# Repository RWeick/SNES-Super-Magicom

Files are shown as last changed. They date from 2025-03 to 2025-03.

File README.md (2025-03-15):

# SNES-Super-Magicom
The Kicad files for the SNES Super Magicom

PCB Thicknesses: 
Mainboard - 1.6 mm
RAM Board - 1.6 mm
System Connector Board - 1.2 mm

The system connector board has been modified to allow for the HiROM mod to be installed. Jumpers are labeled to facilitate operation with or without the mod.

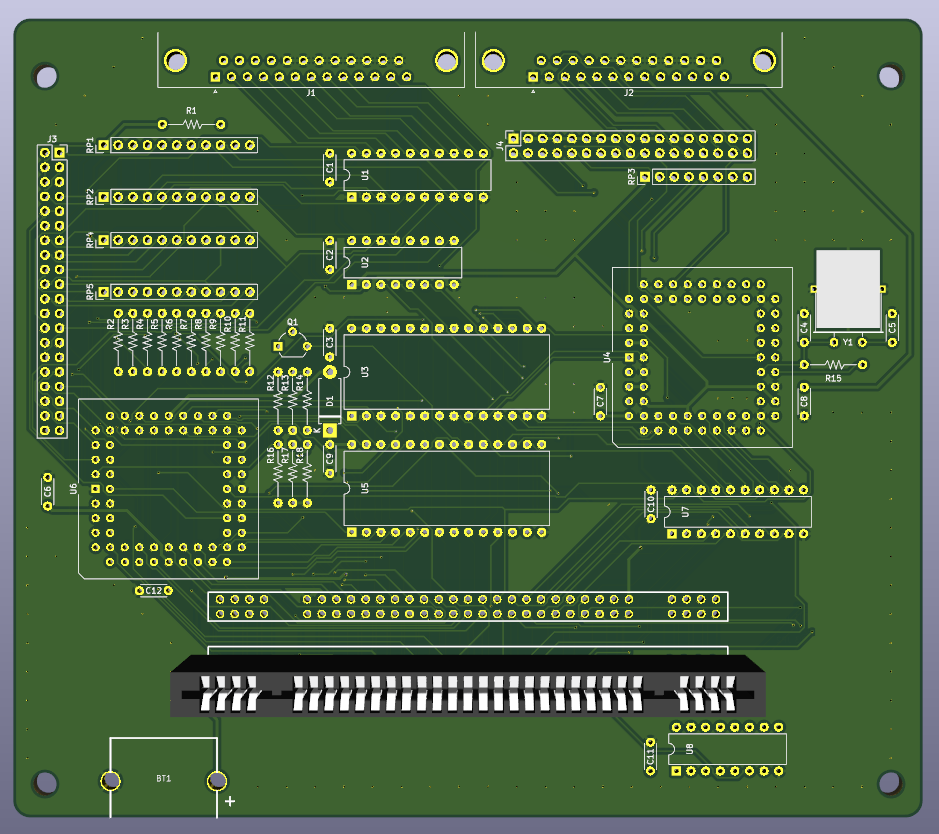
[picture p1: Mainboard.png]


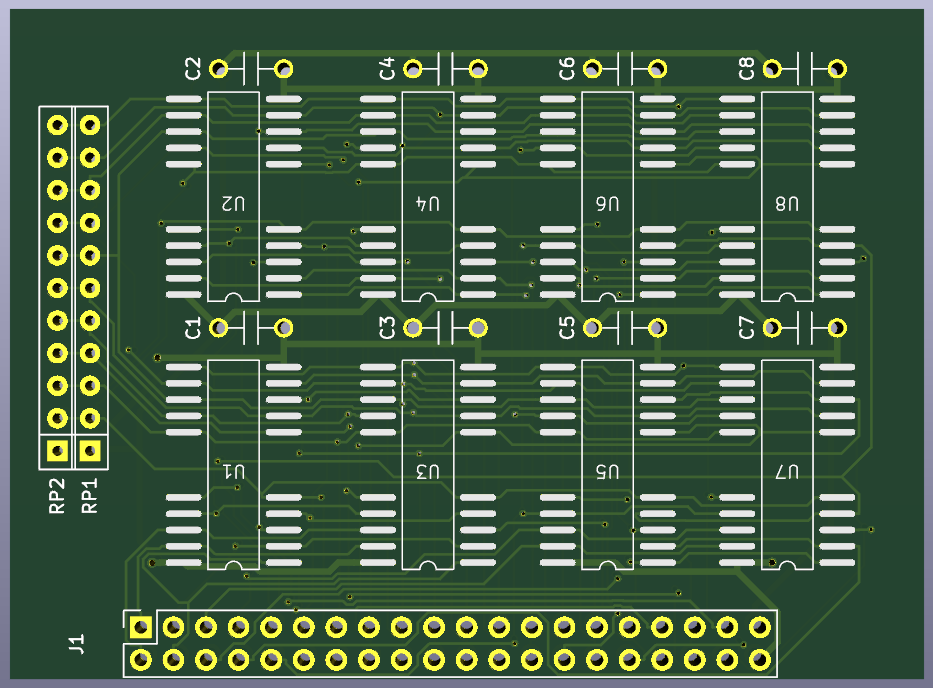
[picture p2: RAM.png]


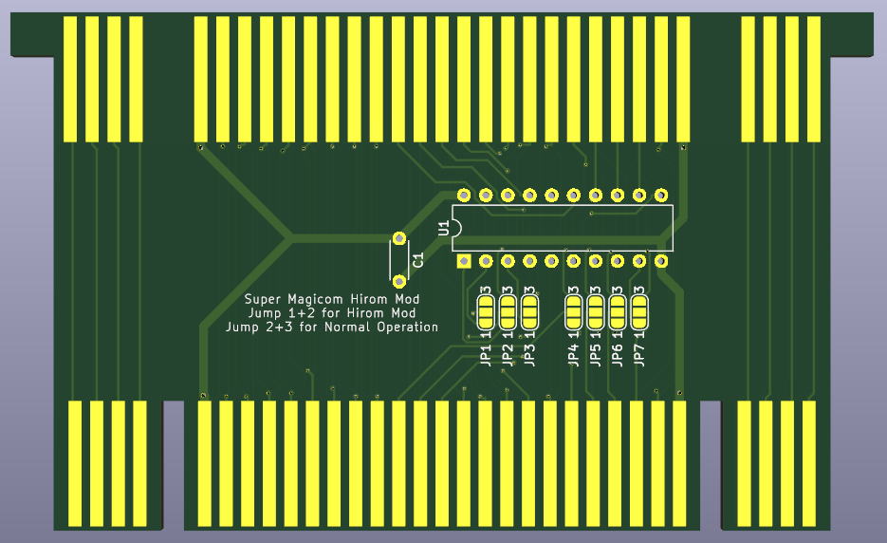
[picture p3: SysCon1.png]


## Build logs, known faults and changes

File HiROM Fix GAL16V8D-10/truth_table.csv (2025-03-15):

/cart_in | a23_in | a22_in | a21_in | a20_in | a17_in | a16_in | a15_in | a14_in | a13_in | - | n/c(16) | /cart_out | a22_out | a21_out | a20_out | a15_out | a14_out | a13_out | - | sourceAddress | - | targetAddress | - | n/c(16)_calc | /cart_out_calc | a22_out_calc | a21_out_calc | a20_out_calc | a15_out_calc | a14_out_calc | a13_out_calc | - | source-target diff? | calc-target match? | 0 | 0 | 0 | 0 | 0 | 0 | 0 | 0 | 0 | 0 | - | 1 | 0 | 0 | 0 | 0 | 0 | 0 | 0 | - | 0x000000 | - | 0x000000 | - | 1
0 | 0 | 0 | 0 | 0 | 0 | 0 | 0 | 0 | 1 | - | 1 | 0 | 0 | 0 | 0 | 0 | 0 | 1 | - | 0x002000 | - | 0x002000 | - | 1 | 0 | 0 | 0 | 0 | 0 | 0 | 1 | - |  | OK
0 | 0 | 0 | 0 | 0 | 0 | 0 | 0 | 1 | 0 | - | 1 | 0 | 0 | 0 | 0 | 0 | 1 | 0 | - | 0x004000 | - | 0x004000 | - | 1 | 0 | 0 | 0 | 0 | 0 | 1 | 0 | - |  | OK
0 | 0 | 0 | 0 | 0 | 0 | 0 | 0 | 1 | 1 | - | 1 | 0 | 0 | 0 | 0 | 0 | 1 | 1 | - | 0x006000 | - | 0x006000 | - | 1 | 0 | 0 | 0 | 0 | 0 | 1 | 1 | - |  | OK
0 | 0 | 0 | 0 | 0 | 0 | 0 | 1 | 0 | 0 | - | 1 | 0 | 0 | 0 | 0 | 1 | 0 | 0 | - | 0x008000 | - | 0x008000 | - | 1 | 0 | 0 | 0 | 0 | 1 | 0 | 0 | - |  | OK
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

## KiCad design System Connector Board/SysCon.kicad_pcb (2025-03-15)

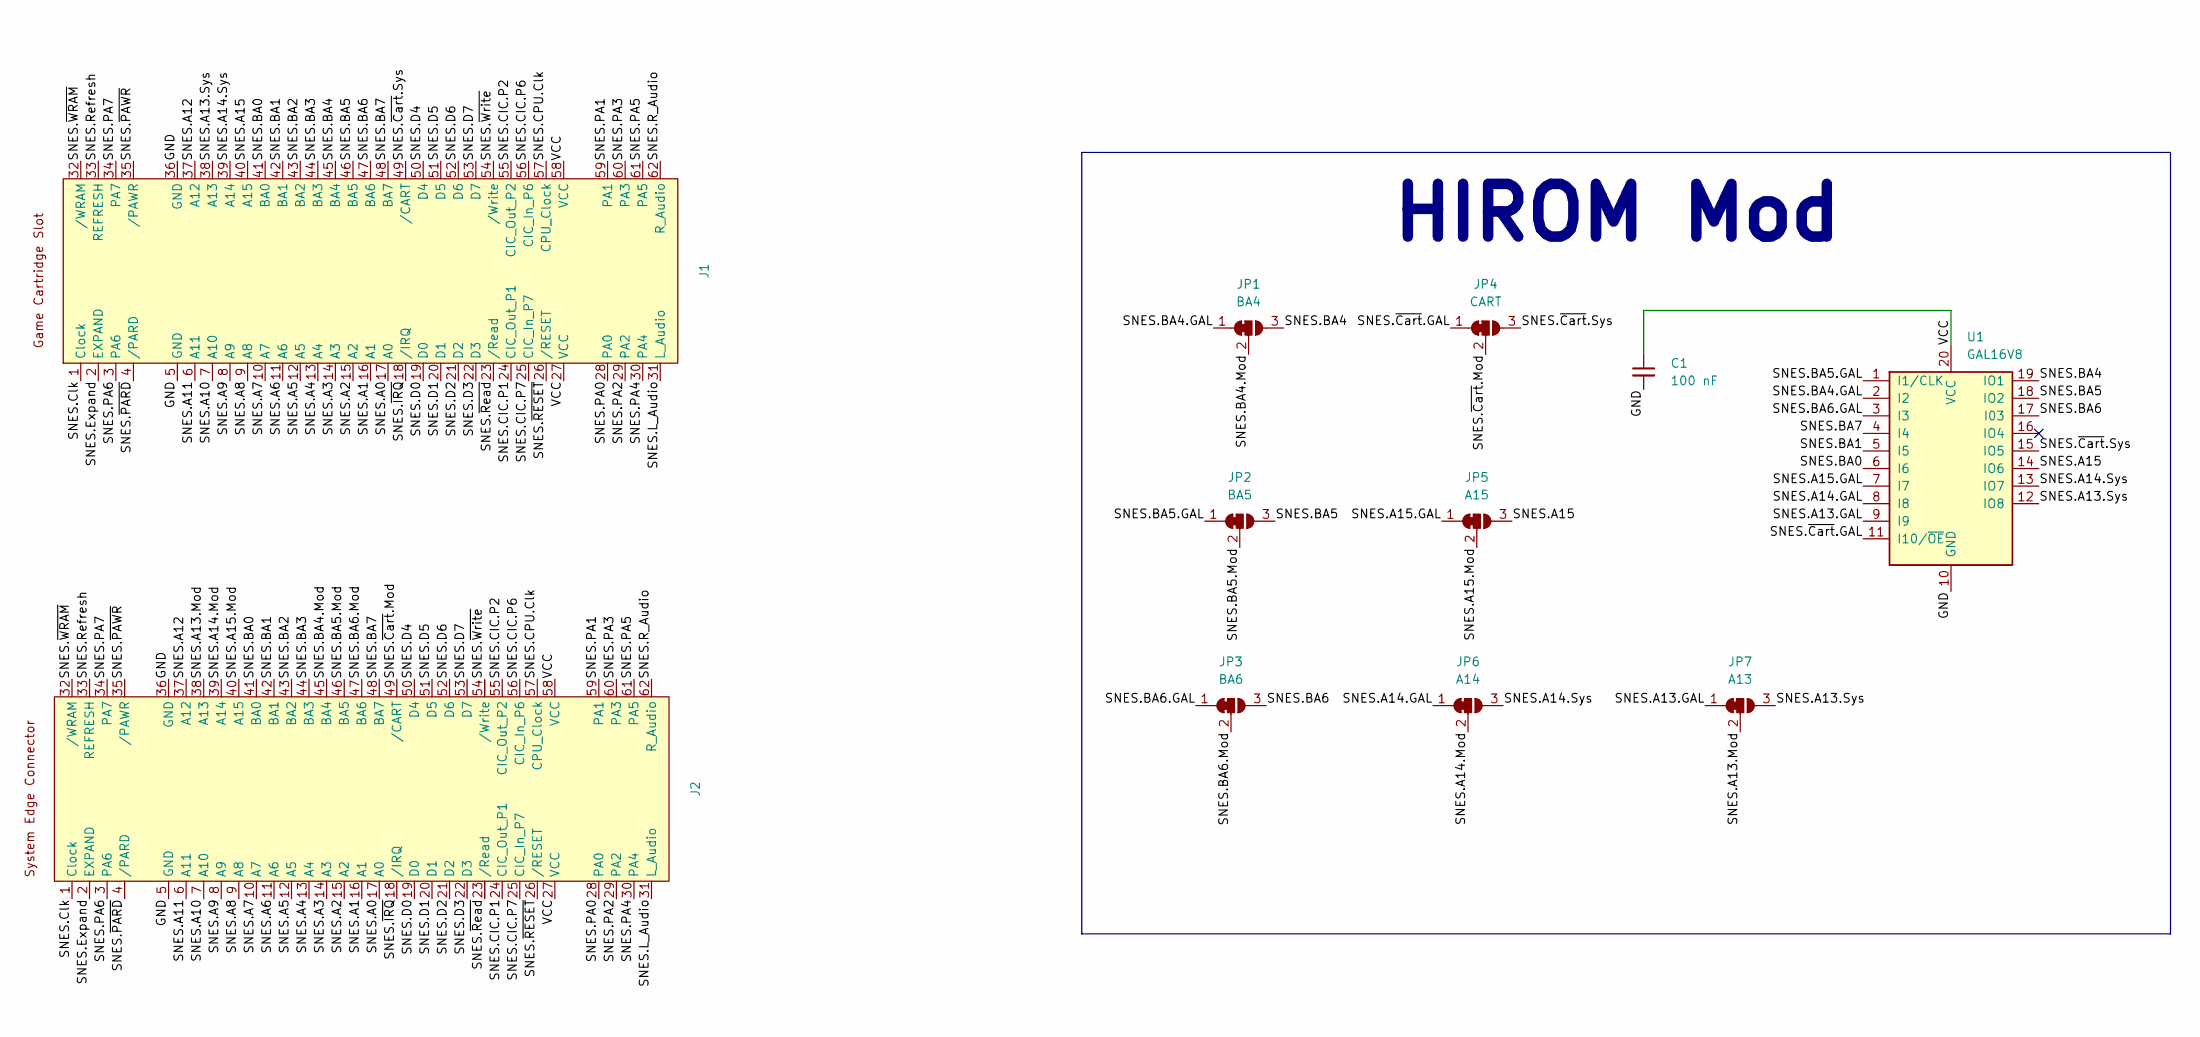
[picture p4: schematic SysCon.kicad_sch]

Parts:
C1: 100 nF; C_Disc_D4.3mm_W1.9mm_P5.00mm
J1: Top Connector
J2: Bottom Connector
JP1: BA4; SolderJumper-3_P1.3mm_Open_RoundedPad1.0x1.5mm_NumberLabels
JP2: BA5; SolderJumper-3_P1.3mm_Open_RoundedPad1.0x1.5mm_NumberLabels
JP3: BA6; SolderJumper-3_P1.3mm_Open_RoundedPad1.0x1.5mm_NumberLabels
JP4: CART; SolderJumper-3_P1.3mm_Open_RoundedPad1.0x1.5mm_NumberLabels
JP5: A15; SolderJumper-3_P1.3mm_Open_RoundedPad1.0x1.5mm_NumberLabels
JP6: A14; SolderJumper-3_P1.3mm_Open_RoundedPad1.0x1.5mm_NumberLabels
JP7: A13; SolderJumper-3_P1.3mm_Open_RoundedPad1.0x1.5mm_NumberLabels
U1: GAL16V8; DIP-20_W7.62mm

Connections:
/GND: C1.2, J1.5 (GND), J1.36 (GND), J2.5 (GND), J2.36 (GND), U1.10 (GND)
/SNES.A0: J1.17 (A0), J2.17 (A0)
/SNES.A1: J1.16 (A1), J2.16 (A1)
/SNES.A2: J1.15 (A2), J2.15 (A2)
/SNES.A3: J1.14 (A3), J2.14 (A3)
/SNES.A4: J1.13 (A4), J2.13 (A4)
/SNES.A5: J1.12 (A5), J2.12 (A5)
/SNES.A6: J1.11 (A6), J2.11 (A6)
/SNES.A7: J1.10 (A7), J2.10 (A7)
/SNES.A8: J1.9 (A8), J2.9 (A8)
/SNES.A9: J1.8 (A9), J2.8 (A9)
/SNES.A10: J1.7 (A10), J2.7 (A10)
/SNES.A11: J1.6 (A11), J2.6 (A11)
/SNES.A12: J1.37 (A12), J2.37 (A12)
/SNES.A13.GAL: JP7.1 (A), U1.9 (I9)
/SNES.A13.Mod: J2.38 (A13), JP7.2 (C)
/SNES.A13.Sys: J1.38 (A13), JP7.3 (B), U1.12 (IO8)
/SNES.A14.GAL: JP6.1 (A), U1.8 (I8)
/SNES.A14.Mod: J2.39 (A14), JP6.2 (C)
/SNES.A14.Sys: J1.39 (A14), JP6.3 (B), U1.13 (IO7)
/SNES.A15: J1.40 (A15), JP5.3 (B), U1.14 (IO6)
/SNES.A15.GAL: JP5.1 (A), U1.7 (I7)
/SNES.A15.Mod: J2.40 (A15), JP5.2 (C)
/SNES.BA0: J1.41 (BA0), J2.41 (BA0), U1.6 (I6)
/SNES.BA1: J1.42 (BA1), J2.42 (BA1), U1.5 (I5)
/SNES.BA2: J1.43 (BA2), J2.43 (BA2)
/SNES.BA3: J1.44 (BA3), J2.44 (BA3)
/SNES.BA4: J1.45 (BA4), JP1.3 (B), U1.19 (IO1)
/SNES.BA4.GAL: JP1.1 (A), U1.2 (I2)
/SNES.BA4.Mod: J2.45 (BA4), JP1.2 (C)
/SNES.BA5: J1.46 (BA5), JP2.3 (B), U1.18 (IO2)
/SNES.BA5.GAL: JP2.1 (A), U1.1 (I1/CLK)
/SNES.BA5.Mod: J2.46 (BA5), JP2.2 (C)
/SNES.BA6: J1.47 (BA6), JP3.3 (B), U1.17 (I03)
/SNES.BA6.GAL: JP3.1 (A), U1.3 (I3)
/SNES.BA6.Mod: J2.47 (BA6), JP3.2 (C)
/SNES.BA7: J1.48 (BA7), J2.48 (BA7), U1.4 (I4)
/SNES.CIC.P1: J1.24 (CIC_Out_P1), J2.24 (CIC_Out_P1)
/SNES.CIC.P2: J1.55 (CIC_Out_P2), J2.55 (CIC_Out_P2)
/SNES.CIC.P6: J1.56 (CIC_In_P6), J2.56 (CIC_In_P6)
/SNES.CIC.P7: J1.25 (CIC_In_P7), J2.25 (CIC_In_P7)
/SNES.CPU.Clk: J1.57 (CPU_Clock), J2.57 (CPU_Clock)
/SNES.Clk: J1.1 (Clock), J2.1 (Clock)
/SNES.D0: J1.19 (D0), J2.19 (D0)
/SNES.D1: J1.20 (D1), J2.20 (D1)
/SNES.D2: J1.21 (D2), J2.21 (D2)
/SNES.D3: J1.22 (D3), J2.22 (D3)
/SNES.D4: J1.50 (D4), J2.50 (D4)
/SNES.D5: J1.51 (D5), J2.51 (D5)
/SNES.D6: J1.52 (D6), J2.52 (D6)
/SNES.D7: J1.53 (D7), J2.53 (D7)
/SNES.Expand: J1.2 (EXPAND), J2.2 (EXPAND)
/SNES.L_Audio: J1.31 (L_Audio), J2.31 (L_Audio)
/SNES.PA0: J1.28 (PA0), J2.28 (PA0)
/SNES.PA1: J1.59 (PA1), J2.59 (PA1)
/SNES.PA2: J1.29 (PA2), J2.29 (PA2)
/SNES.PA3: J1.60 (PA3), J2.60 (PA3)
/SNES.PA4: J1.30 (PA4), J2.30 (PA4)
/SNES.PA5: J1.61 (PA5), J2.61 (PA5)
/SNES.PA6: J1.3 (PA6), J2.3 (PA6)
/SNES.PA7: J1.34 (PA7), J2.34 (PA7)
/SNES.R_Audio: J1.62 (R_Audio), J2.62 (R_Audio)
/SNES.Refresh: J1.33 (REFRESH), J2.33 (REFRESH)
/SNES.~Cart.GAL: JP4.1 (A), U1.11 (I10/~OE)
/SNES.~Cart.Mod: J2.49 (/CART), JP4.2 (C)
/SNES.~Cart.Sys: J1.49 (/CART), JP4.3 (B), U1.15 (IO5)
/SNES.~IRQ: J1.18 (/IRQ), J2.18 (/IRQ)
/SNES.~PARD: J1.4 (/PARD), J2.4 (/PARD)
/SNES.~PAWR: J1.35 (/PAWR), J2.35 (/PAWR)
/SNES.~RESET: J1.26 (/RESET), J2.26 (/RESET)
/SNES.~Read: J1.23 (/Read), J2.23 (/Read)
/SNES.~WRAM: J1.32 (/WRAM), J2.32 (/WRAM)
/SNES.~Write: J1.54 (/Write), J2.54 (/Write)
/VCC: C1.1, J1.27 (VCC), J1.58 (VCC), J2.27 (VCC), J2.58 (VCC), U1.20 (VCC)

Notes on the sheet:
HIROM Mod

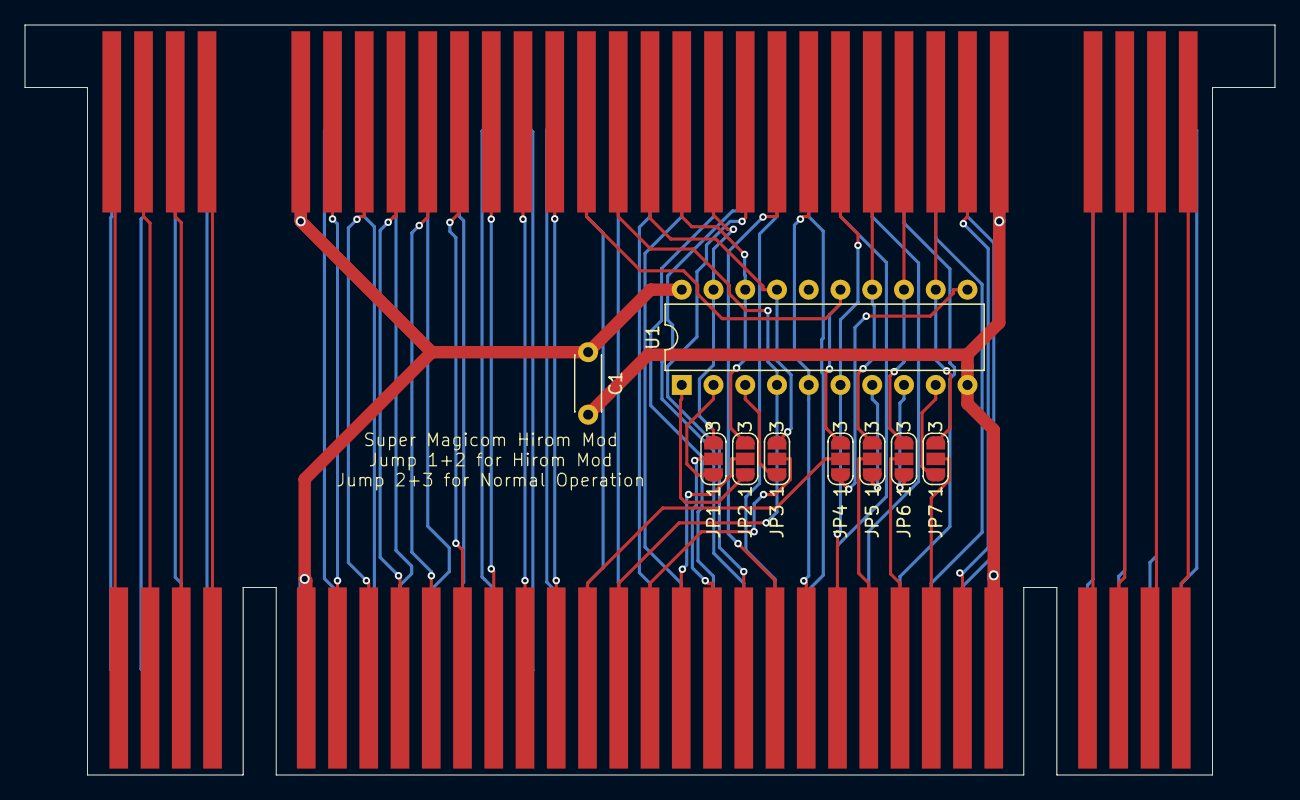
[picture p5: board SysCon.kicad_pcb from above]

Board: 2 copper layers, 100.0 x 60.0 mm, 11 parts (0 on the bottom side), 74 nets.

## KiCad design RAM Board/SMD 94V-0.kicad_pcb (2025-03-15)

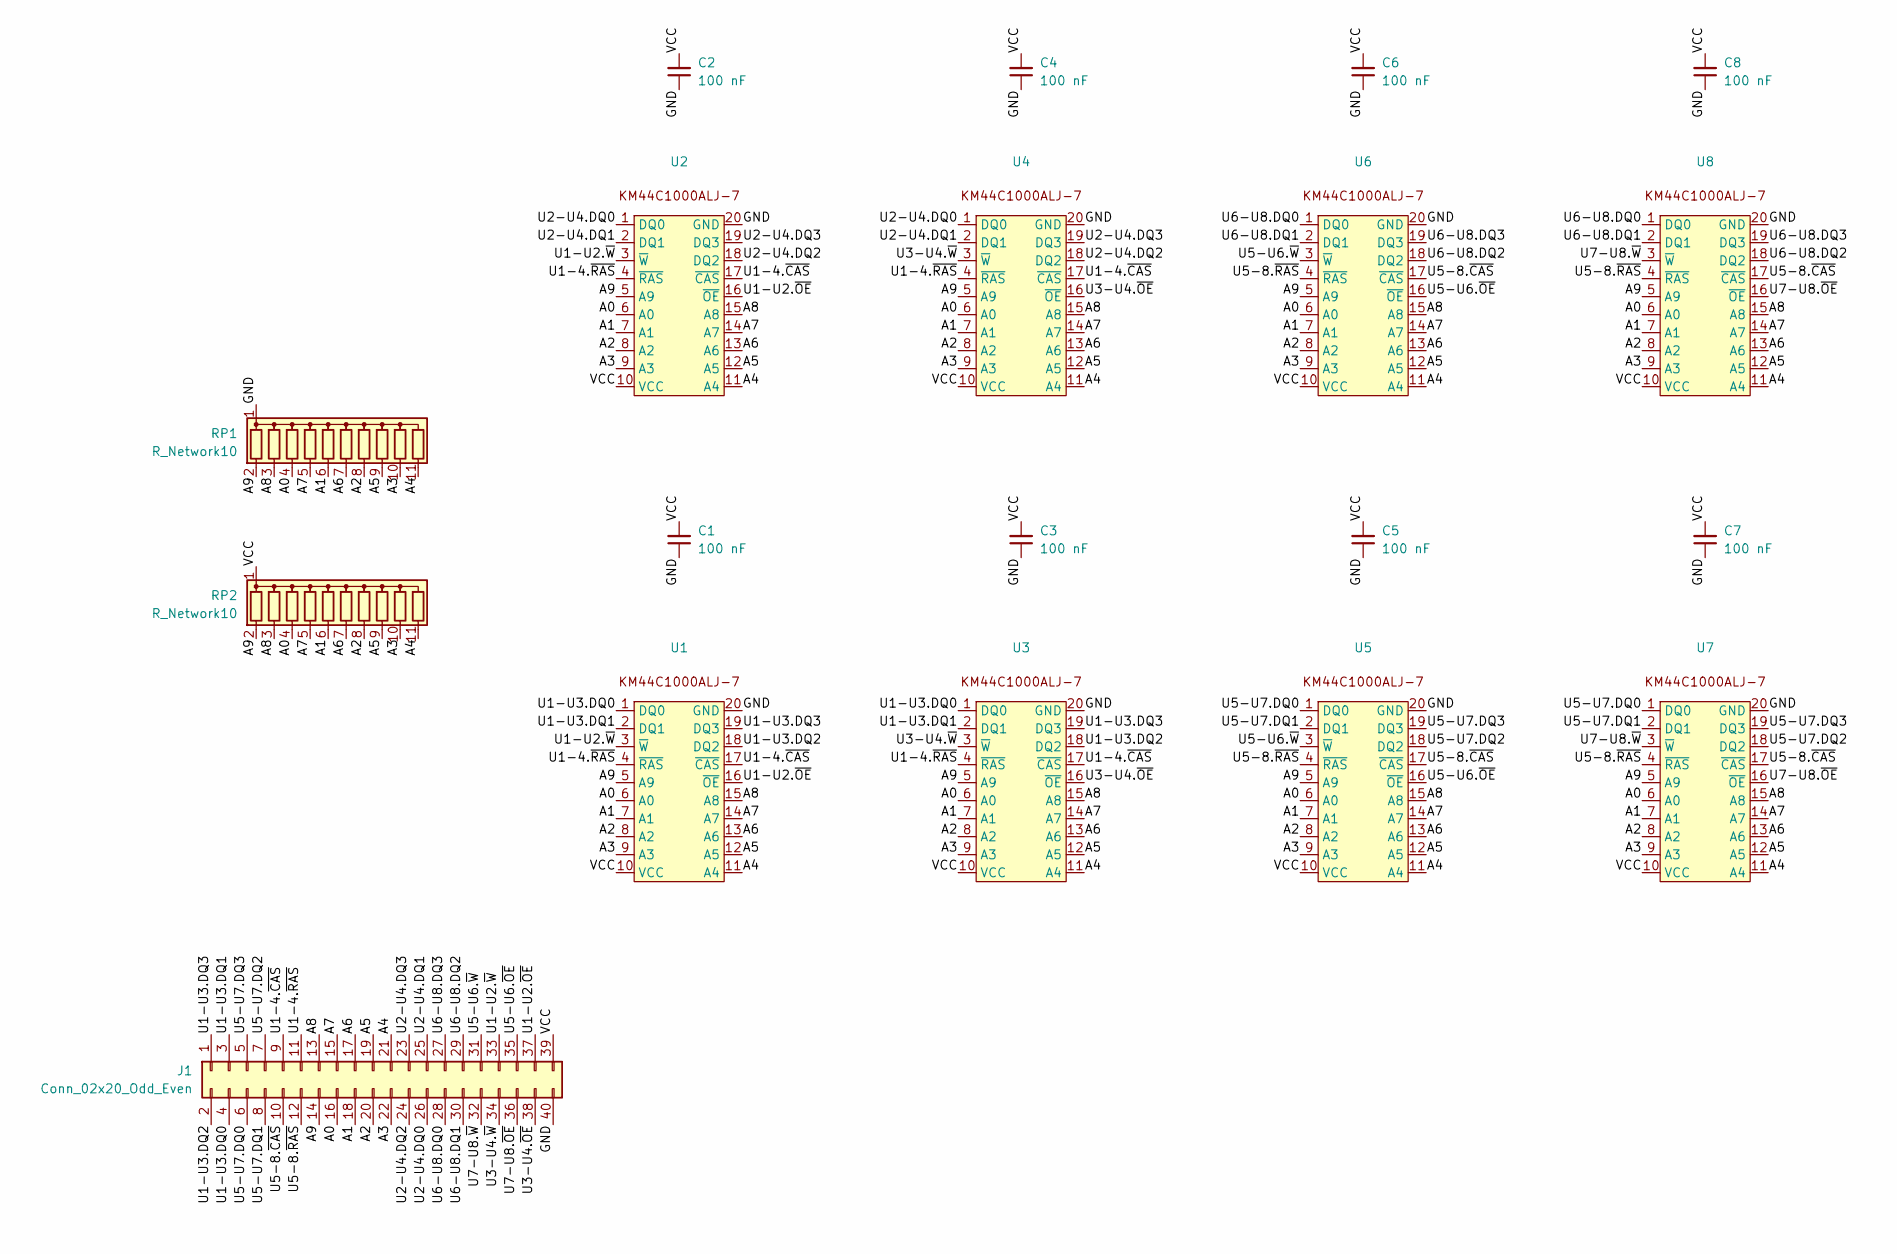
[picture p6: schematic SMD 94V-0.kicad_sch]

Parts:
C1, C2, C3, C4, C5, C6, C7, C8: 100 nF; Capacitor
J1: Conn_02x20_Odd_Even; PinHeader_2x20_P2.54mm_Vertical
RP1, RP2: R_Network10; R_Array_SIP11
U1, U2, U3, U4, U5, U6, U7, U8: KM44C1000ALJ-7

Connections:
/A0: J1.16, RP1.4 (R3), RP2.4 (R3), U1.6 (A0), U2.6 (A0), U3.6 (A0), U4.6 (A0), U5.6 (A0), U6.6 (A0), U7.6 (A0), U8.6 (A0)
/A1: J1.18, RP1.6 (R5), RP2.6 (R5), U1.7 (A1), U2.7 (A1), U3.7 (A1), U4.7 (A1), U5.7 (A1), U6.7 (A1), U7.7 (A1), U8.7 (A1)
/A2: J1.20, RP1.8 (R7), RP2.8 (R7), U1.8 (A2), U2.8 (A2), U3.8 (A2), U4.8 (A2), U5.8 (A2), U6.8 (A2), U7.8 (A2), U8.8 (A2)
/A3: J1.22, RP1.10 (R9), RP2.10 (R9), U1.9 (A3), U2.9 (A3), U3.9 (A3), U4.9 (A3), U5.9 (A3), U6.9 (A3), U7.9 (A3), U8.9 (A3)
/A4: J1.21, RP1.11 (R10), RP2.11 (R10), U1.11 (A4), U2.11 (A4), U3.11 (A4), U4.11 (A4), U5.11 (A4), U6.11 (A4), U7.11 (A4), U8.11 (A4)
/A5: J1.19, RP1.9 (R8), RP2.9 (R8), U1.12 (A5), U2.12 (A5), U3.12 (A5), U4.12 (A5), U5.12 (A5), U6.12 (A5), U7.12 (A5), U8.12 (A5)
/A6: J1.17, RP1.7 (R6), RP2.7 (R6), U1.13 (A6), U2.13 (A6), U3.13 (A6), U4.13 (A6), U5.13 (A6), U6.13 (A6), U7.13 (A6), U8.13 (A6)
/A7: J1.15, RP1.5 (R4), RP2.5 (R4), U1.14 (A7), U2.14 (A7), U3.14 (A7), U4.14 (A7), U5.14 (A7), U6.14 (A7), U7.14 (A7), U8.14 (A7)
/A8: J1.13, RP1.3 (R2), RP2.3 (R2), U1.15 (A8), U2.15 (A8), U3.15 (A8), U4.15 (A8), U5.15 (A8), U6.15 (A8), U7.15 (A8), U8.15 (A8)
/A9: J1.14, RP1.2 (R1), RP2.2 (R1), U1.5 (A9), U2.5 (A9), U3.5 (A9), U4.5 (A9), U5.5 (A9), U6.5 (A9), U7.5 (A9), U8.5 (A9)
/GND: C1.1, C2.1, C3.1, C4.1, C5.1, C6.1, C7.1, C8.1, J1.40, RP1.1 (common), U1.20 (GND), U2.20 (GND), U3.20 (GND), U4.20 (GND), U5.20 (GND), U6.20 (GND), U7.20 (GND), U8.20 (GND)
/U1-4.~CAS: J1.9, U1.17 (~CAS), U2.17 (~CAS), U3.17 (~CAS), U4.17 (~CAS)
/U1-4.~RAS: J1.11, U1.4 (~RAS), U2.4 (~RAS), U3.4 (~RAS), U4.4 (~RAS)
/U1-U2.~OE: J1.37, U1.16 (~OE), U2.16 (~OE)
/U1-U2.~W: J1.33, U1.3 (~W), U2.3 (~W)
/U1-U3.DQ0: J1.4, U1.1 (DQ0), U3.1 (DQ0)
/U1-U3.DQ1: J1.3, U1.2 (DQ1), U3.2 (DQ1)
/U1-U3.DQ2: J1.2, U1.18 (DQ2), U3.18 (DQ2)
/U1-U3.DQ3: J1.1, U1.19 (DQ3), U3.19 (DQ3)
/U2-U4.DQ0: J1.26, U2.1 (DQ0), U4.1 (DQ0)
/U2-U4.DQ1: J1.25, U2.2 (DQ1), U4.2 (DQ1)
/U2-U4.DQ2: J1.24, U2.18 (DQ2), U4.18 (DQ2)
/U2-U4.DQ3: J1.23, U2.19 (DQ3), U4.19 (DQ3)
/U3-U4.~OE: J1.38, U3.16 (~OE), U4.16 (~OE)
/U3-U4.~W: J1.34, U3.3 (~W), U4.3 (~W)
/U5-8.~CAS: J1.10, U5.17 (~CAS), U6.17 (~CAS), U7.17 (~CAS), U8.17 (~CAS)
/U5-8.~RAS: J1.12, U5.4 (~RAS), U6.4 (~RAS), U7.4 (~RAS), U8.4 (~RAS)
/U5-U6.~OE: J1.35, U5.16 (~OE), U6.16 (~OE)
/U5-U6.~W: J1.31, U5.3 (~W), U6.3 (~W)
/U5-U7.DQ0: J1.6, U5.1 (DQ0), U7.1 (DQ0)
/U5-U7.DQ1: J1.8, U5.2 (DQ1), U7.2 (DQ1)
/U5-U7.DQ2: J1.7, U5.18 (DQ2), U7.18 (DQ2)
/U5-U7.DQ3: J1.5, U5.19 (DQ3), U7.19 (DQ3)
/U6-U8.DQ0: J1.28, U6.1 (DQ0), U8.1 (DQ0)
/U6-U8.DQ1: J1.30, U6.2 (DQ1), U8.2 (DQ1)
/U6-U8.DQ2: J1.29, U6.18 (DQ2), U8.18 (DQ2)
/U6-U8.DQ3: J1.27, U6.19 (DQ3), U8.19 (DQ3)
/U7-U8.~OE: J1.36, U7.16 (~OE), U8.16 (~OE)
/U7-U8.~W: J1.32, U7.3 (~W), U8.3 (~W)
/VCC: C1.2, C2.2, C3.2, C4.2, C5.2, C6.2, C7.2, C8.2, J1.39, RP2.1 (common), U1.10 (VCC), U2.10 (VCC), U3.10 (VCC), U4.10 (VCC), U5.10 (VCC), U6.10 (VCC), U7.10 (VCC), U8.10 (VCC)

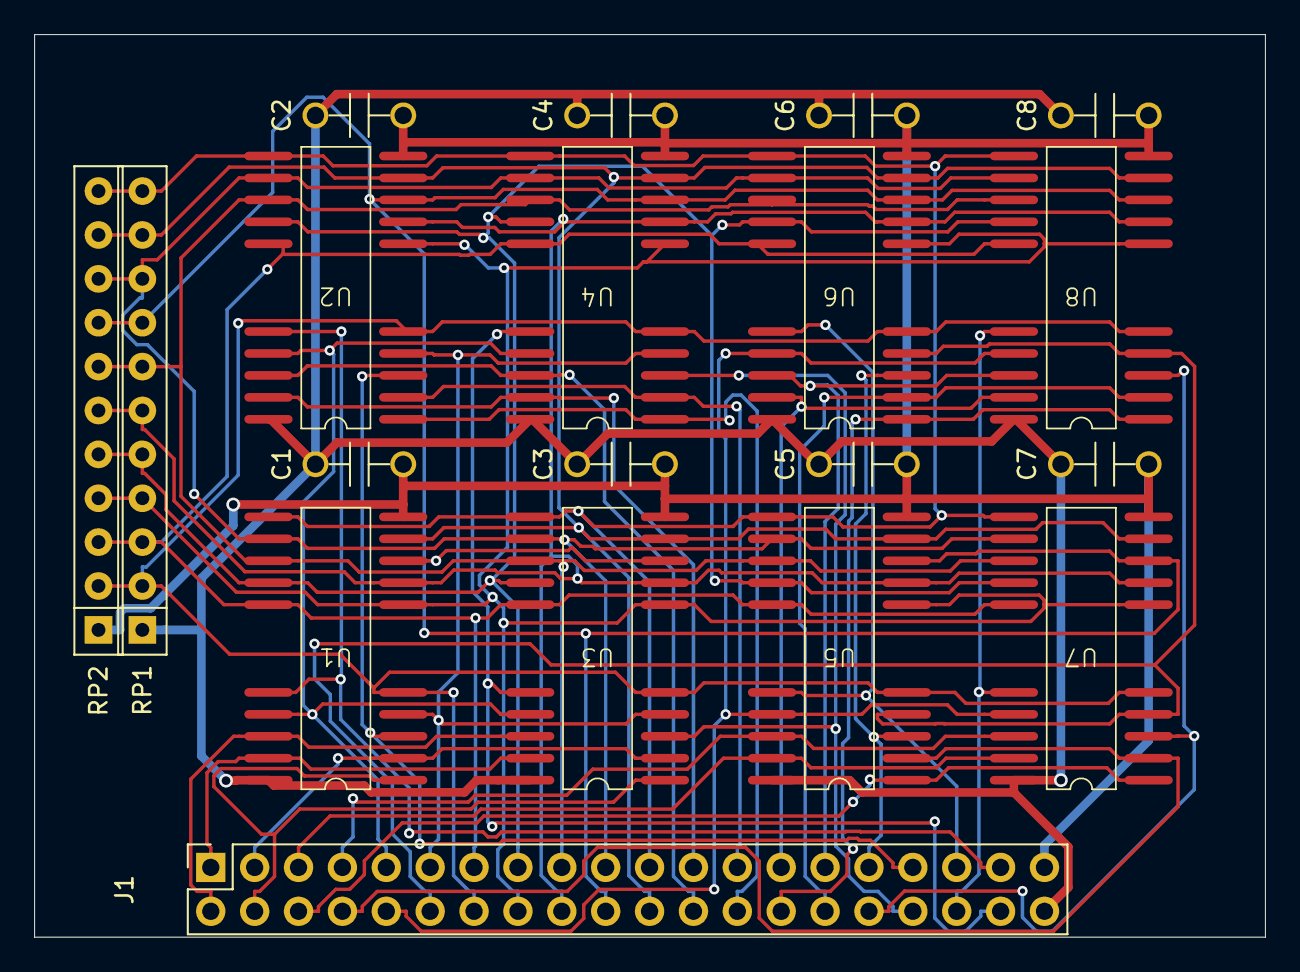
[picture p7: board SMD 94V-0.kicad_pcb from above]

Board: 2 copper layers, 71.3 x 52.2 mm, 19 parts (0 on the bottom side), 40 nets.

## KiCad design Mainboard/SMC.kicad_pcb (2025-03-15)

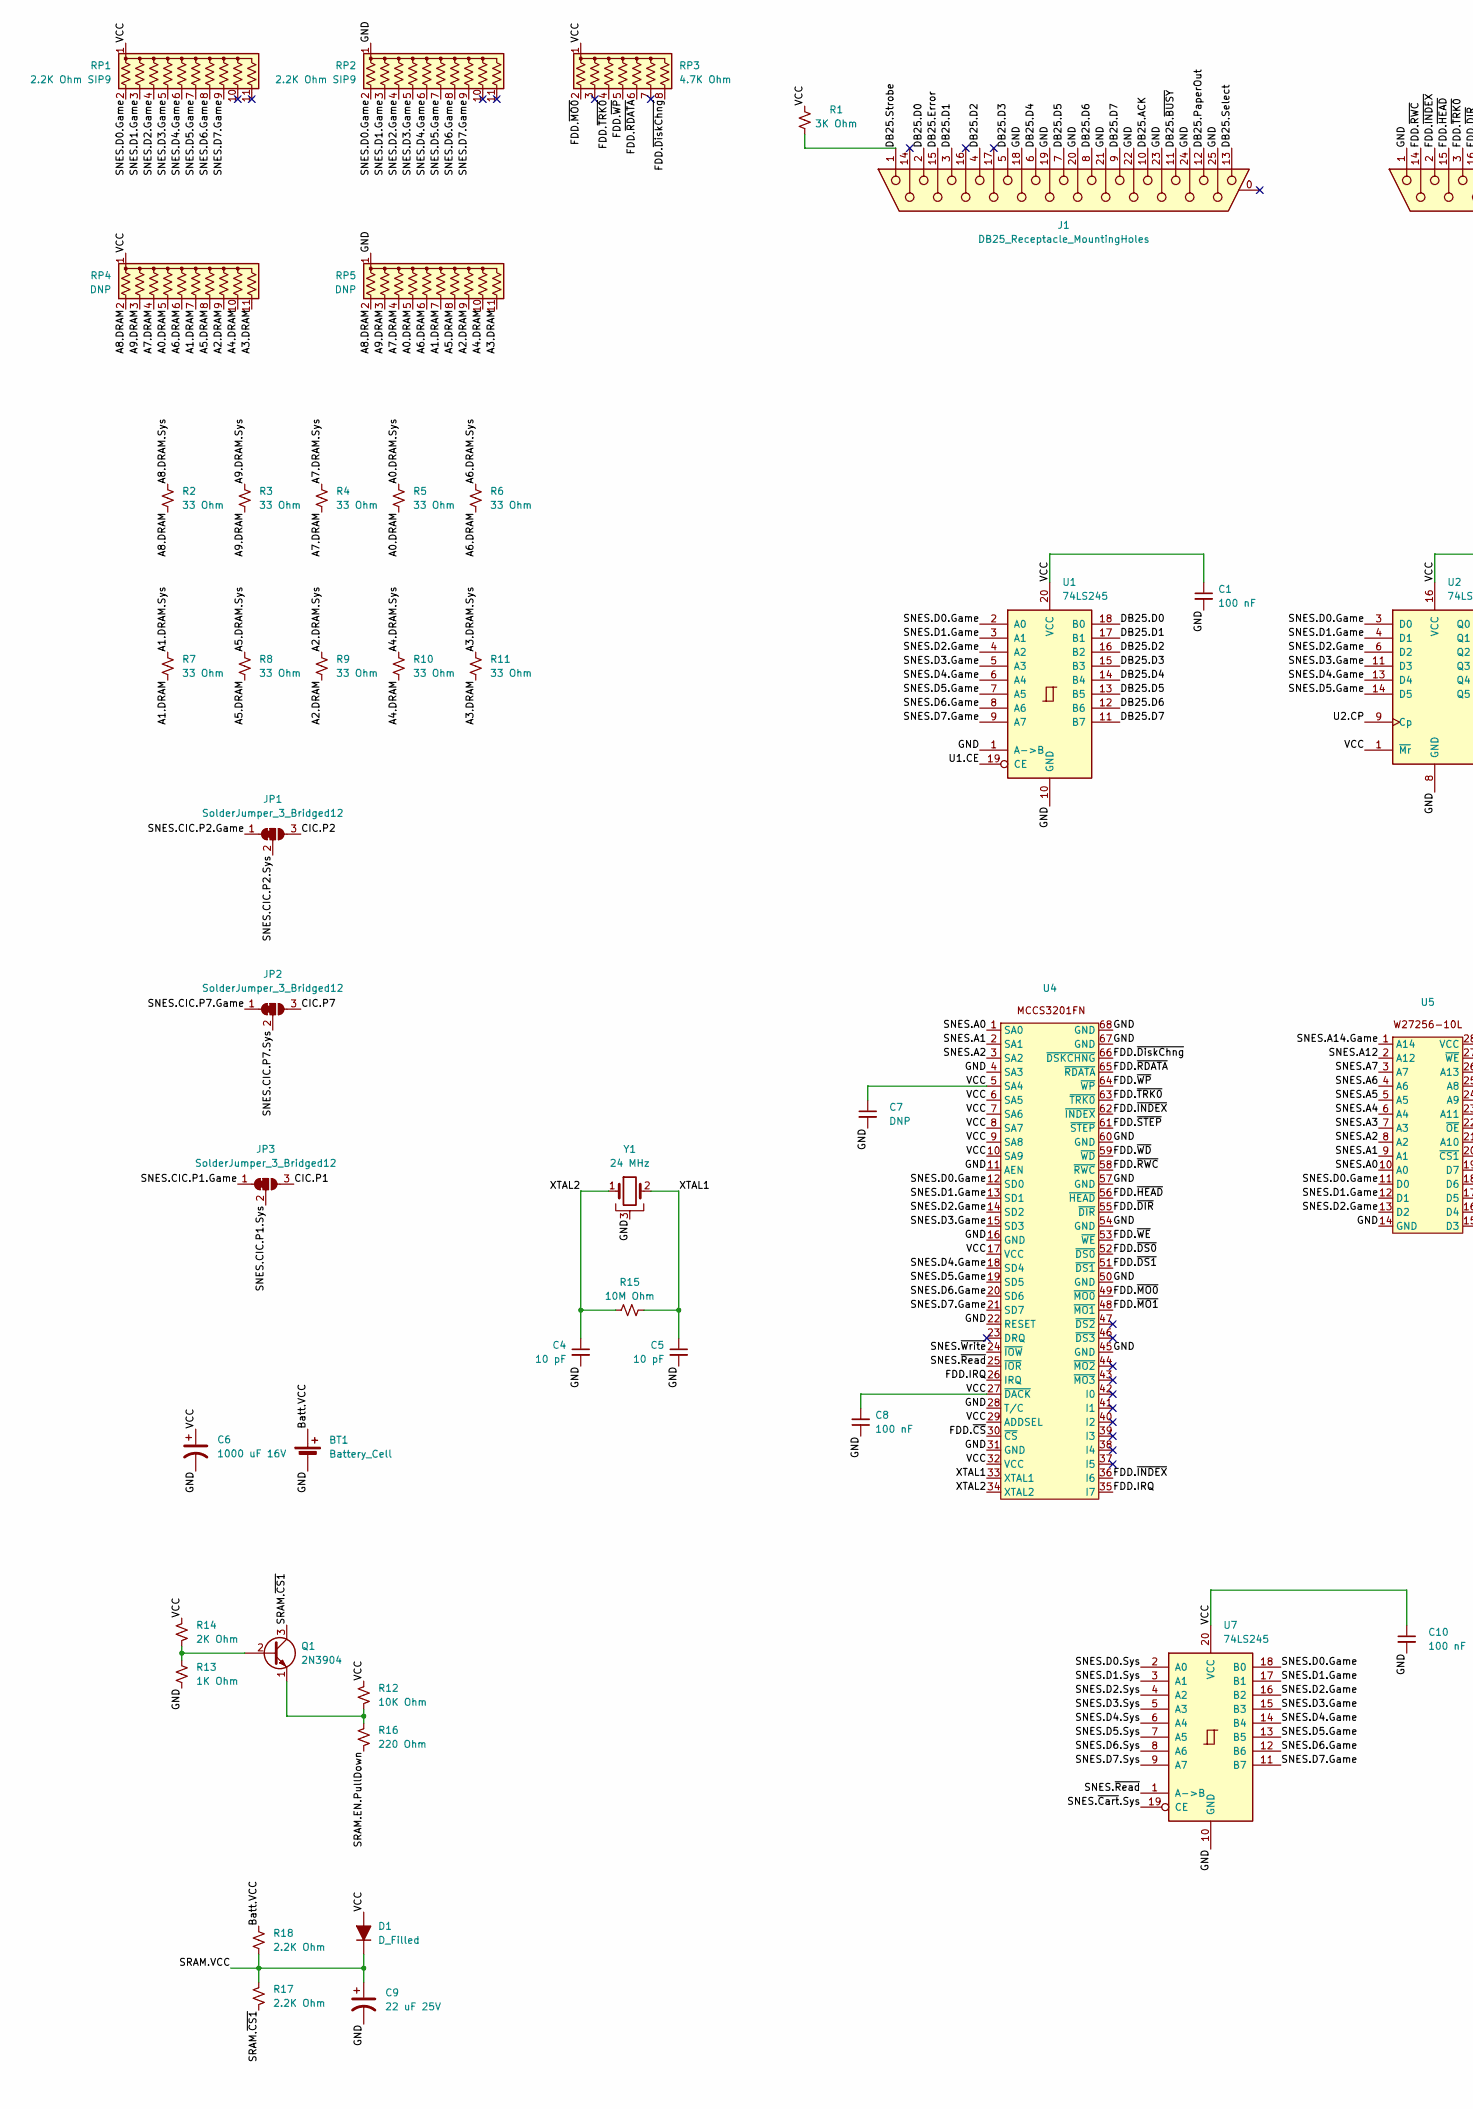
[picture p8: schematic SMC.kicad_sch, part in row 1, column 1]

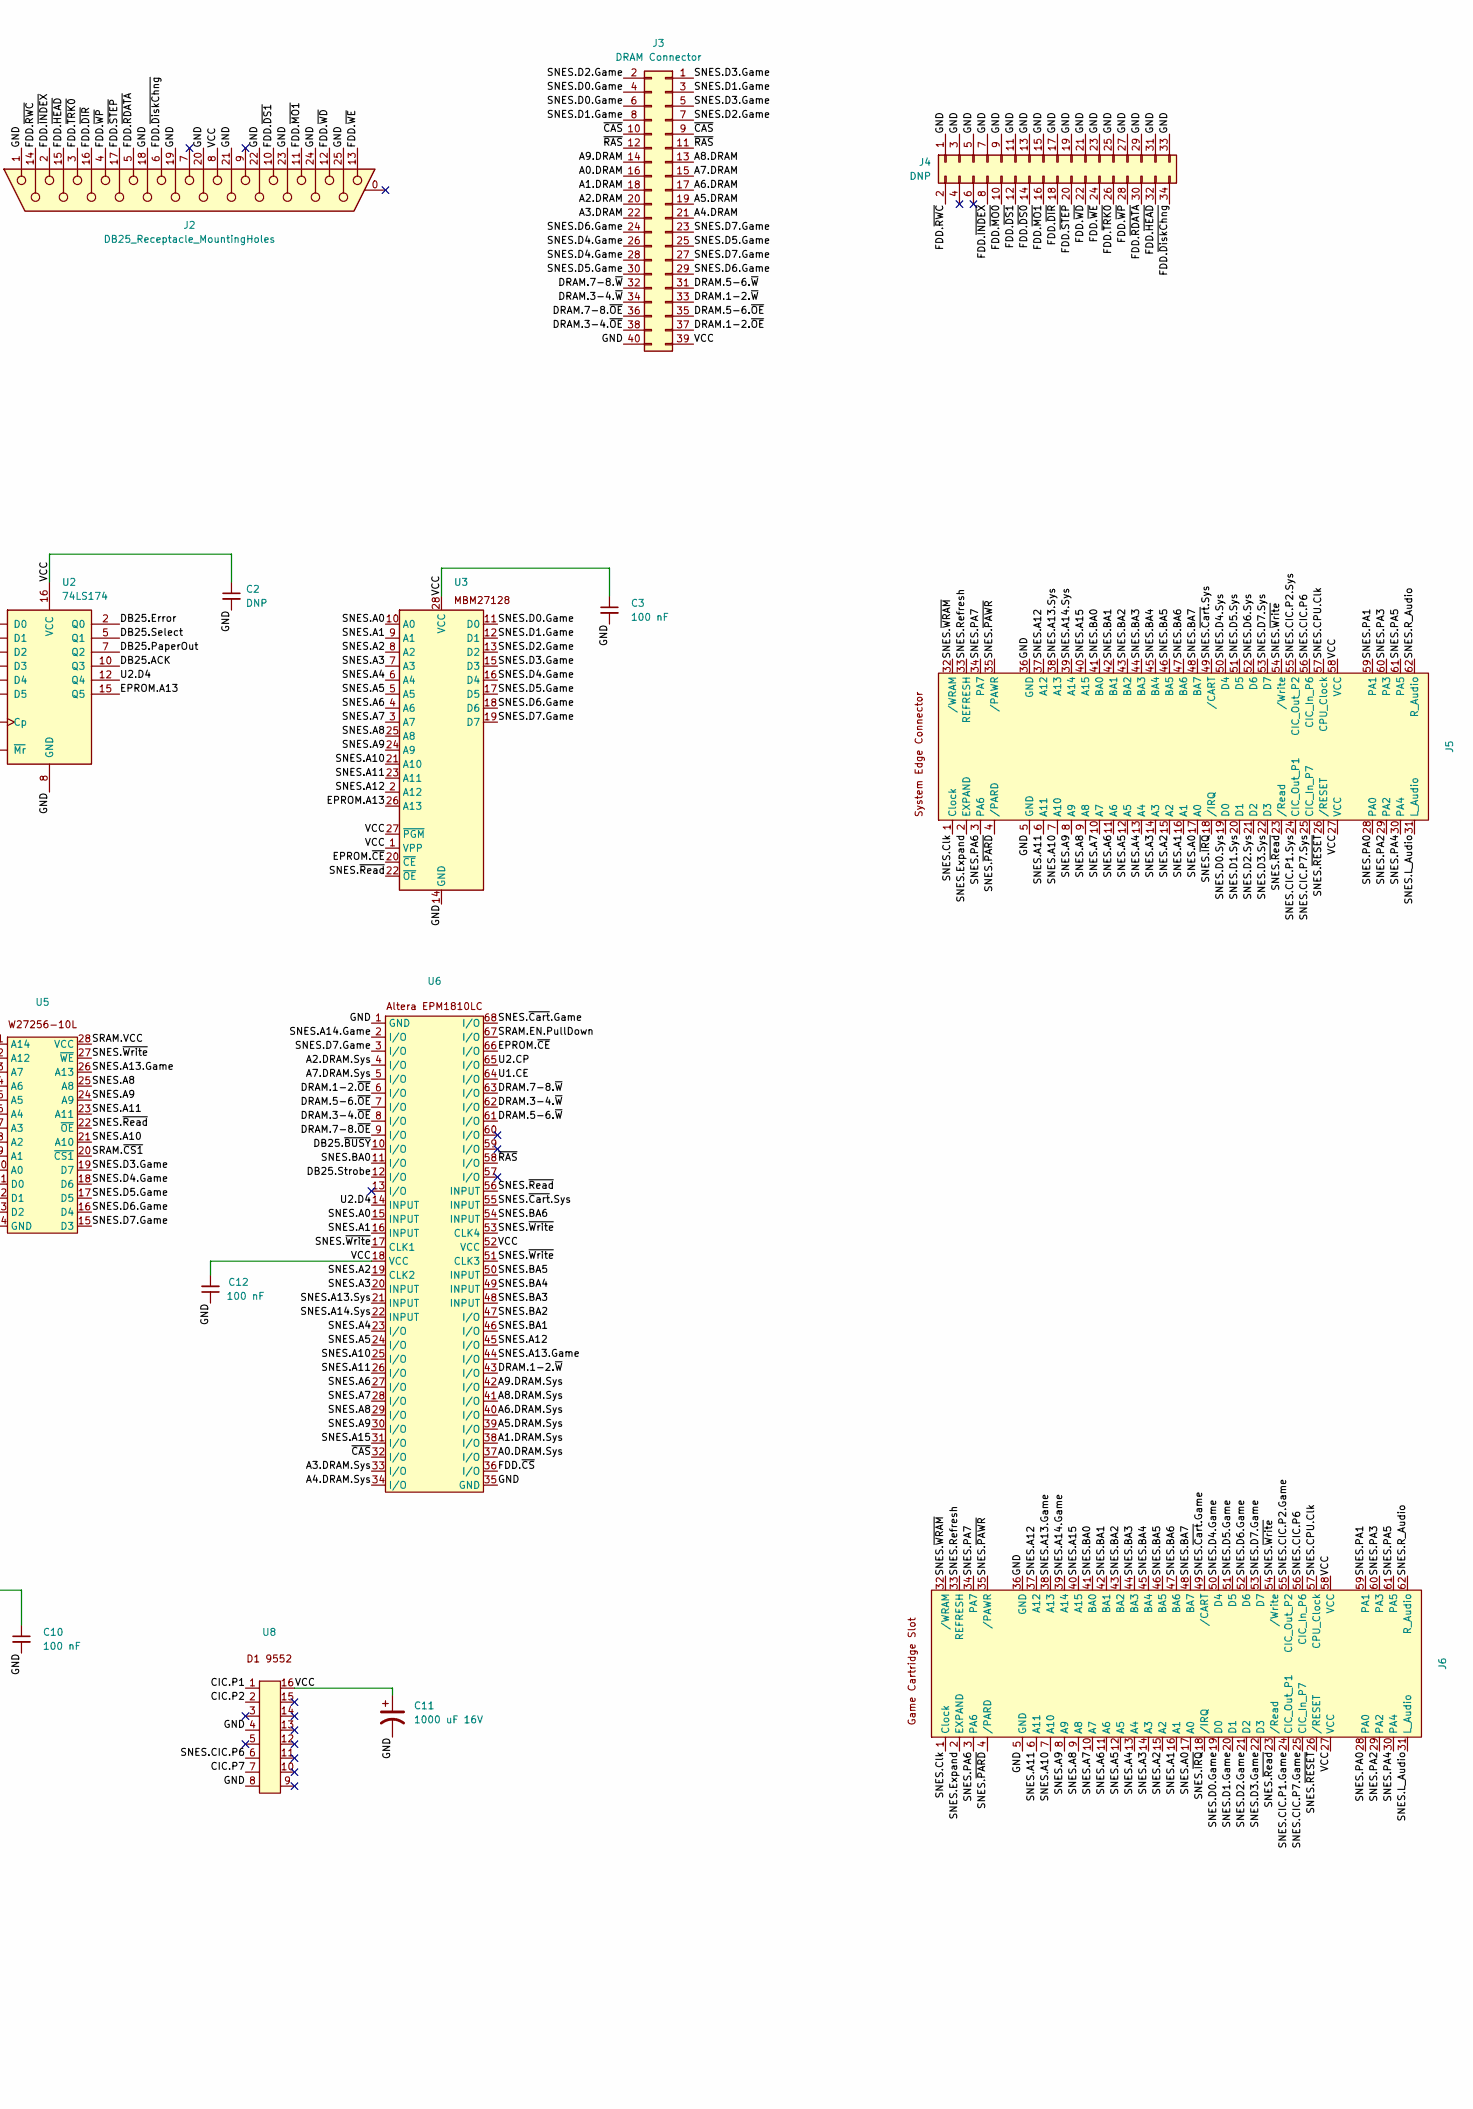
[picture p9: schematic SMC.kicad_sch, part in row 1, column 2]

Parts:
BT1: Battery_Cell; Battery
C1, C3, C8, C10, C12: 100 nF; C_Disc_D4.3mm_W1.9mm_P5.00mm
C2, C7: DNP; C_Disc_D4.3mm_W1.9mm_P5.00mm
C4, C5: 10 pF; C_Disc_D4.3mm_W1.9mm_P5.00mm
C6, C11: 1000 uF 16V; C_Disc_D4.3mm_W1.9mm_P5.00mm
C9: 22 uF 25V; C_Disc_D4.3mm_W1.9mm_P5.00mm
D1: D_Filled; D_DO-15_P10.16mm_Horizontal
J1, J2: DB25_Receptacle_MountingHoles; DSUB-25_Female_Horizontal_P2.77x2.84mm_EdgePinOffset4.94mm_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
J3: DRAM Connector; PinHeader_2x20_P2.54mm_Vertical
J4: DNP; PinHeader_2x17_P2.54mm_Vertical
J5: SNES Connector Slot
J6: SNES Cartridge Slot
JP1, JP2, JP3: SolderJumper_3_Bridged12; SolderJumper-3_P1.3mm_Open_RoundedPad1.0x1.5mm_NumberLabels
Q1: 2N3904; TO-92_Wide
R1: 3K Ohm; R_Axial_DIN0207_L6.3mm_D2.5mm_P10.16mm_Horizontal
R2, R3, R4, R5, R6, R7, R8, R9, R10, R11: 33 Ohm; R_Axial_DIN0207_L6.3mm_D2.5mm_P10.16mm_Horizontal
R12: 10K Ohm; R_Axial_DIN0207_L6.3mm_D2.5mm_P10.16mm_Horizontal
R13: 1K Ohm; R_Axial_DIN0207_L6.3mm_D2.5mm_P10.16mm_Horizontal
R14: 2K Ohm; R_Axial_DIN0207_L6.3mm_D2.5mm_P10.16mm_Horizontal
R15: 10M Ohm; R_Axial_DIN0207_L6.3mm_D2.5mm_P10.16mm_Horizontal
R16: 220 Ohm; R_Axial_DIN0207_L6.3mm_D2.5mm_P10.16mm_Horizontal
R17, R18: 2.2K Ohm; R_Axial_DIN0207_L6.3mm_D2.5mm_P10.16mm_Horizontal
RP1, RP2: 2.2K Ohm SIP9; PinHeader_1x11_P2.54mm_Vertical
RP3: 4.7K Ohm; PinHeader_1x08_P2.54mm_Vertical
RP4, RP5: DNP; PinHeader_1x11_P2.54mm_Vertical
U1, U7: 74LS245; DIP-20_W7.62mm
U2: 74LS174; DIP-16_W7.62mm
U3: 27128; DIP-28_W15.24mm
U4, U6: PLCC-68_THT-Socket
U5: DIP-28_W15.24mm
U8: DIP-16_W7.62mm
Y1: 24 MHz; Crystal_HC18-U_Horizontal_1EP_style2

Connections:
/A0.DRAM: J3.16, R5.1, RP4.5 (R4), RP5.5 (R4)
/A0.DRAM.Sys: R5.2, U6.37 (I/O)
/A1.DRAM: J3.18, R7.1, RP4.7 (R6), RP5.7 (R6)
/A1.DRAM.Sys: R7.2, U6.38 (I/O)
/A2.DRAM: J3.20, R9.1, RP4.9 (R8), RP5.9 (R8)
/A2.DRAM.Sys: R9.2, U6.4 (I/O)
/A3.DRAM: J3.22, R11.1, RP4.11 (R10), RP5.11 (R10)
/A3.DRAM.Sys: R11.2, U6.33 (I/O)
/A4.DRAM: J3.21, R10.1, RP4.10 (R9), RP5.10 (R9)
/A4.DRAM.Sys: R10.2, U6.34 (I/O)
/A5.DRAM: J3.19, R8.1, RP4.8 (R7), RP5.8 (R7)
/A5.DRAM.Sys: R8.2, U6.39 (I/O)
/A6.DRAM: J3.17, R6.1, RP4.6 (R5), RP5.6 (R5)
/A6.DRAM.Sys: R6.2, U6.40 (I/O)
/A7.DRAM: J3.15, R4.1, RP4.4 (R3), RP5.4 (R3)
/A7.DRAM.Sys: R4.2, U6.5 (I/O)
/A8.DRAM: J3.13, R2.1, RP4.2 (R1), RP5.2 (R1)
/A8.DRAM.Sys: R2.2, U6.41 (I/O)
/A9.DRAM: J3.14, R3.1, RP4.3 (R2), RP5.3 (R2)
/A9.DRAM.Sys: R3.2, U6.42 (I/O)
/Batt.VCC: BT1.1 (+), R18.2
/CIC.P1: JP3.3 (B), U8.1
/CIC.P2: JP1.3 (B), U8.2
/CIC.P7: JP2.3 (B), U8.7
/DB25.ACK: J1.10, U2.10 (Q3)
/DB25.D0: J1.2, U1.18 (B0)
/DB25.D1: J1.3, U1.17 (B1)
/DB25.D2: J1.4, U1.16 (B2)
/DB25.D3: J1.5, U1.15 (B3)
/DB25.D4: J1.6, U1.14 (B4)
/DB25.D5: J1.7, U1.13 (B5)
/DB25.D6: J1.8, U1.12 (B6)
/DB25.D7: J1.9, U1.11 (B7)
/DB25.Error: J1.15, U2.2 (Q0)
/DB25.PaperOut: J1.12, U2.7 (Q2)
/DB25.Select: J1.13, U2.5 (Q1)
/DB25.Strobe: J1.1, R1.2, U6.12 (I/O)
/DB25.~BUSY: J1.11, U6.10 (I/O)
/DRAM.1-2.~OE: J3.37, U6.6 (I/O)
/DRAM.1-2.~W: J3.33, U6.43 (I/O)
/DRAM.3-4.~OE: J3.38, U6.8 (I/O)
/DRAM.3-4.~W: J3.34, U6.62 (I/O)
/DRAM.5-6.~OE: J3.35, U6.7 (I/O)
/DRAM.5-6.~W: J3.31, U6.61 (I/O)
/DRAM.7-8.~OE: J3.36, U6.9 (I/O)
/DRAM.7-8.~W: J3.32, U6.63 (I/O)
/EPROM.A13: U2.15 (Q5), U3.26 (A13)
/EPROM.~CE: U3.20 (~CE), U6.66 (I/O)
/FDD.IRQ: U4.26 (IRQ), U4.35 (I7)
/FDD.~CS: U4.30 (~CS), U6.36 (I/O)
/FDD.~DIR: J2.16, J4.18, U4.55 (~DIR)
/FDD.~DS0: J4.14, U4.52 (~DS0)
/FDD.~DS1: J2.10, J4.12, U4.51 (~DS1)
/FDD.~DiskChng: J2.6, J4.34, RP3.8 (R7), U4.66 (~DSKCHNG)
/FDD.~HEAD: J2.15, J4.32, U4.56 (~HEAD)
/FDD.~INDEX: J2.2, J4.8, U4.36 (I6), U4.62 (~INDEX)
/FDD.~MO0: J4.10, RP3.2 (R1), U4.49 (~MO0)
/FDD.~MO1: J2.11, J4.16, U4.48 (~MO1)
/FDD.~RDATA: J2.5, J4.30, RP3.6 (R5), U4.65 (~RDATA)
/FDD.~RWC: J2.14, J4.2, U4.58 (~RWC)
/FDD.~STEP: J2.17, J4.20, U4.61 (~STEP)
/FDD.~TRK0: J2.3, J4.26, RP3.4 (R3), U4.63 (~TRK0)
/FDD.~WD: J2.12, J4.22, U4.59 (~WD)
/FDD.~WE: J2.13, J4.24, U4.53 (~WE)
/FDD.~WP: J2.4, J4.28, RP3.5 (R4), U4.64 (~WP)
/GND: BT1.2 (-), C1.2, C2.2, C3.2, C4.2, C5.2, C6.2, C7.2, C8.1, C9.2, C10.2, C11.2, C12.1, J1.18, J1.19, J1.20, J1.21, J1.22, J1.23, J1.24, J1.25, J2.1, J2.18, J2.19, J2.20, J2.21, J2.22, J2.23, J2.24, J2.25, J3.40, J4.1, J4.3, J4.5, J4.7, J4.9, J4.11, J4.13, J4.15, J4.17, J4.19, J4.21, J4.23, J4.25, J4.27, J4.29, J4.31, J4.33, J5.5 (GND), J5.36 (GND), J6.5 (GND), J6.36 (GND), R13.1, RP2.1 (common), RP5.1 (common), U1.1 (A->B), U1.10 (GND), U2.8 (GND), U3.14 (GND), U4.4 (SA3), U4.11 (AEN), U4.16 (GND), U4.22 (RESET), U4.28 (T/C), U4.31 (GND), U4.45 (GND), U4.50 (GND), U4.54 (GND), U4.57 (GND), U4.60 (GND), U4.67 (GND), U4.68 (GND), U5.14 (GND), U6.1 (GND), U6.35 (GND), U7.10 (GND), U8.4, U8.8, Y1.3
/SNES.A0: J5.17 (A0), J6.17 (A0), U3.10 (A0), U4.1 (SA0), U5.10 (A0), U6.15 (INPUT)
/SNES.A1: J5.16 (A1), J6.16 (A1), U3.9 (A1), U4.2 (SA1), U5.9 (A1), U6.16 (INPUT)
/SNES.A2: J5.15 (A2), J6.15 (A2), U3.8 (A2), U4.3 (SA2), U5.8 (A2), U6.19 (CLK2)
/SNES.A3: J5.14 (A3), J6.14 (A3), U3.7 (A3), U5.7 (A3), U6.20 (INPUT)
/SNES.A4: J5.13 (A4), J6.13 (A4), U3.6 (A4), U5.6 (A4), U6.23 (I/O)
/SNES.A5: J5.12 (A5), J6.12 (A5), U3.5 (A5), U5.5 (A5), U6.24 (I/O)
/SNES.A6: J5.11 (A6), J6.11 (A6), U3.4 (A6), U5.4 (A6), U6.27 (I/O)
/SNES.A7: J5.10 (A7), J6.10 (A7), U3.3 (A7), U5.3 (A7), U6.28 (I/O)
/SNES.A8: J5.9 (A8), J6.9 (A8), U3.25 (A8), U5.25 (A8), U6.29 (I/O)
/SNES.A9: J5.8 (A9), J6.8 (A9), U3.24 (A9), U5.24 (A9), U6.30 (I/O)
/SNES.A10: J5.7 (A10), J6.7 (A10), U3.21 (A10), U5.21 (A10), U6.25 (I/O)
/SNES.A11: J5.6 (A11), J6.6 (A11), U3.23 (A11), U5.23 (A11), U6.26 (I/O)
/SNES.A12: J5.37 (A12), J6.37 (A12), U3.2 (A12), U5.2 (A12), U6.45 (I/O)
/SNES.A13.Game: J6.38 (A13), U5.26 (A13), U6.44 (I/O)
/SNES.A13.Sys: J5.38 (A13), U6.21 (INPUT)
/SNES.A14.Game: J6.39 (A14), U5.1 (A14), U6.2 (I/O)
/SNES.A14.Sys: J5.39 (A14), U6.22 (INPUT)
/SNES.A15: J5.40 (A15), J6.40 (A15), U6.31 (I/O)
/SNES.BA0: J5.41 (BA0), J6.41 (BA0), U6.11 (I/O)
/SNES.BA1: J5.42 (BA1), J6.42 (BA1), U6.46 (I/O)
/SNES.BA2: J5.43 (BA2), J6.43 (BA2), U6.47 (I/O)
/SNES.BA3: J5.44 (BA3), J6.44 (BA3), U6.48 (INPUT)
/SNES.BA4: J5.45 (BA4), J6.45 (BA4), U6.49 (INPUT)
/SNES.BA5: J5.46 (BA5), J6.46 (BA5), U6.50 (INPUT)
/SNES.BA6: J5.47 (BA6), J6.47 (BA6), U6.54 (INPUT)
/SNES.BA7: J5.48 (BA7), J6.48 (BA7)
/SNES.CIC.P1.Game: J6.24 (CIC_Out_P1), JP3.1 (A)
/SNES.CIC.P1.Sys: J5.24 (CIC_Out_P1), JP3.2 (C)
/SNES.CIC.P2.Game: J6.55 (CIC_Out_P2), JP1.1 (A)
/SNES.CIC.P2.Sys: J5.55 (CIC_Out_P2), JP1.2 (C)
/SNES.CIC.P6: J5.56 (CIC_In_P6), J6.56 (CIC_In_P6), U8.6
/SNES.CIC.P7.Game: J6.25 (CIC_In_P7), JP2.1 (A)
/SNES.CIC.P7.Sys: J5.25 (CIC_In_P7), JP2.2 (C)
/SNES.CPU.Clk: J5.57 (CPU_Clock), J6.57 (CPU_Clock)
/SNES.Clk: J5.1 (Clock), J6.1 (Clock)
/SNES.D0.Game: J3.4, J3.6, J6.19 (D0), RP1.2 (R1), RP2.2 (R1), U1.2 (A0), U2.3 (D0), U3.11 (D0), U4.12 (SD0), U5.11 (D0), U7.18 (B0)
/SNES.D0.Sys: J5.19 (D0), U7.2 (A0)
/SNES.D1.Game: J3.3, J3.8, J6.20 (D1), RP1.3 (R2), RP2.3 (R2), U1.3 (A1), U2.4 (D1), U3.12 (D1), U4.13 (SD1), U5.12 (D1), U7.17 (B1)
/SNES.D1.Sys: J5.20 (D1), U7.3 (A1)
/SNES.D2.Game: J3.2, J3.7, J6.21 (D2), RP1.4 (R3), RP2.4 (R3), U1.4 (A2), U2.6 (D2), U3.13 (D2), U4.14 (SD2), U5.13 (D2), U7.16 (B2)
/SNES.D2.Sys: J5.21 (D2), U7.4 (A2)
/SNES.D3.Game: J3.1, J3.5, J6.22 (D3), RP1.5 (R4), RP2.5 (R4), U1.5 (A3), U2.11 (D3), U3.15 (D3), U4.15 (SD3), U5.19 (D7), U7.15 (B3)
/SNES.D3.Sys: J5.22 (D3), U7.5 (A3)
/SNES.D4.Game: J3.26, J3.28, J6.50 (D4), RP1.6 (R5), RP2.6 (R5), U1.6 (A4), U2.13 (D4), U3.16 (D4), U4.18 (SD4), U5.18 (D6), U7.14 (B4)
/SNES.D4.Sys: J5.50 (D4), U7.6 (A4)
/SNES.D5.Game: J3.25, J3.30, J6.51 (D5), RP1.7 (R6), RP2.7 (R6), U1.7 (A5), U2.14 (D5), U3.17 (D5), U4.19 (SD5), U5.17 (D5), U7.13 (B5)
/SNES.D5.Sys: J5.51 (D5), U7.7 (A5)
/SNES.D6.Game: J3.24, J3.29, J6.52 (D6), RP1.8 (R7), RP2.8 (R7), U1.8 (A6), U3.18 (D6), U4.20 (SD6), U5.16 (D4), U7.12 (B6)
/SNES.D6.Sys: J5.52 (D6), U7.8 (A6)
/SNES.D7.Game: J3.23, J3.27, J6.53 (D7), RP1.9 (R8), RP2.9 (R8), U1.9 (A7), U3.19 (D7), U4.21 (SD7), U5.15 (D3), U6.3 (I/O), U7.11 (B7)
/SNES.D7.Sys: J5.53 (D7), U7.9 (A7)
/SNES.Expand: J5.2 (EXPAND), J6.2 (EXPAND)
/SNES.L_Audio: J5.31 (L_Audio), J6.31 (L_Audio)
/SNES.PA0: J5.28 (PA0), J6.28 (PA0)
/SNES.PA1: J5.59 (PA1), J6.59 (PA1)
/SNES.PA2: J5.29 (PA2), J6.29 (PA2)
/SNES.PA3: J5.60 (PA3), J6.60 (PA3)
/SNES.PA4: J5.30 (PA4), J6.30 (PA4)
/SNES.PA5: J5.61 (PA5), J6.61 (PA5)
/SNES.PA6: J5.3 (PA6), J6.3 (PA6)
/SNES.PA7: J5.34 (PA7), J6.34 (PA7)
/SNES.R_Audio: J5.62 (R_Audio), J6.62 (R_Audio)
/SNES.Refresh: J5.33 (REFRESH), J6.33 (REFRESH)
/SNES.~Cart.Game: J6.49 (/CART), U6.68 (I/O)
/SNES.~Cart.Sys: J5.49 (/CART), U6.55 (INPUT), U7.19 (CE)
/SNES.~IRQ: J5.18 (/IRQ), J6.18 (/IRQ)
/SNES.~PARD: J5.4 (/PARD), J6.4 (/PARD)
/SNES.~PAWR: J5.35 (/PAWR), J6.35 (/PAWR)
/SNES.~RESET: J5.26 (/RESET), J6.26 (/RESET)
/SNES.~Read: J5.23 (/Read), J6.23 (/Read), U3.22 (~OE), U4.25 (~IOR), U5.22 (~OE), U6.56 (INPUT), U7.1 (A->B)
/SNES.~WRAM: J5.32 (/WRAM), J6.32 (/WRAM)
/SNES.~Write: J5.54 (/Write), J6.54 (/Write), U4.24 (~IOW), U5.27 (~WE), U6.17 (CLK1), U6.51 (CLK3), U6.53 (CLK4)
/SRAM.EN.PullDown: R16.2, U6.67 (I/O)
/SRAM.VCC: C9.1, D1.1 (K), R17.1, R18.1, U5.28 (VCC)
/SRAM.~CS1: Q1.3 (C), R17.2, U5.20 (~CS1)
/U1.CE: U1.19 (CE), U6.64 (I/O)
/U2.CP: U2.9 (Cp), U6.65 (I/O)
/U2.D4: U2.12 (Q4), U6.14 (INPUT)
/VCC: C1.1, C2.1, C3.1, C6.1, C7.1, C8.2, C10.1, C11.1, C12.2, D1.2 (A), J2.8, J3.39, J5.27 (VCC), J5.58 (VCC), J6.27 (VCC), J6.58 (VCC), R1.1, R12.1, R14.1, RP1.1 (common), RP3.1 (common), RP4.1 (common), U1.20 (VCC), U2.1 (~Mr), U2.16 (VCC), U3.1 (VPP), U3.27 (~PGM), U3.28 (VCC), U4.5 (SA4), U4.6 (SA5), U4.7 (SA6), U4.8 (SA7), U4.9 (SA8), U4.10 (SA9), U4.17 (VCC), U4.27 (~DACK), U4.29 (ADDSEL), U4.32 (VCC), U6.18 (VCC), U6.52 (VCC), U7.20 (VCC), U8.16
/XTAL1: C5.1, R15.2, U4.33 (XTAL1), Y1.2
/XTAL2: C4.1, R15.1, U4.34 (XTAL2), Y1.1
/~CAS: J3.9, J3.10, U6.32 (I/O)
/~RAS: J3.11, J3.12, U6.58 (I/O)
unnamed: Q1.2 (B), R13.2, R14.2
unnamed: Q1.1 (E), R12.2, R16.1

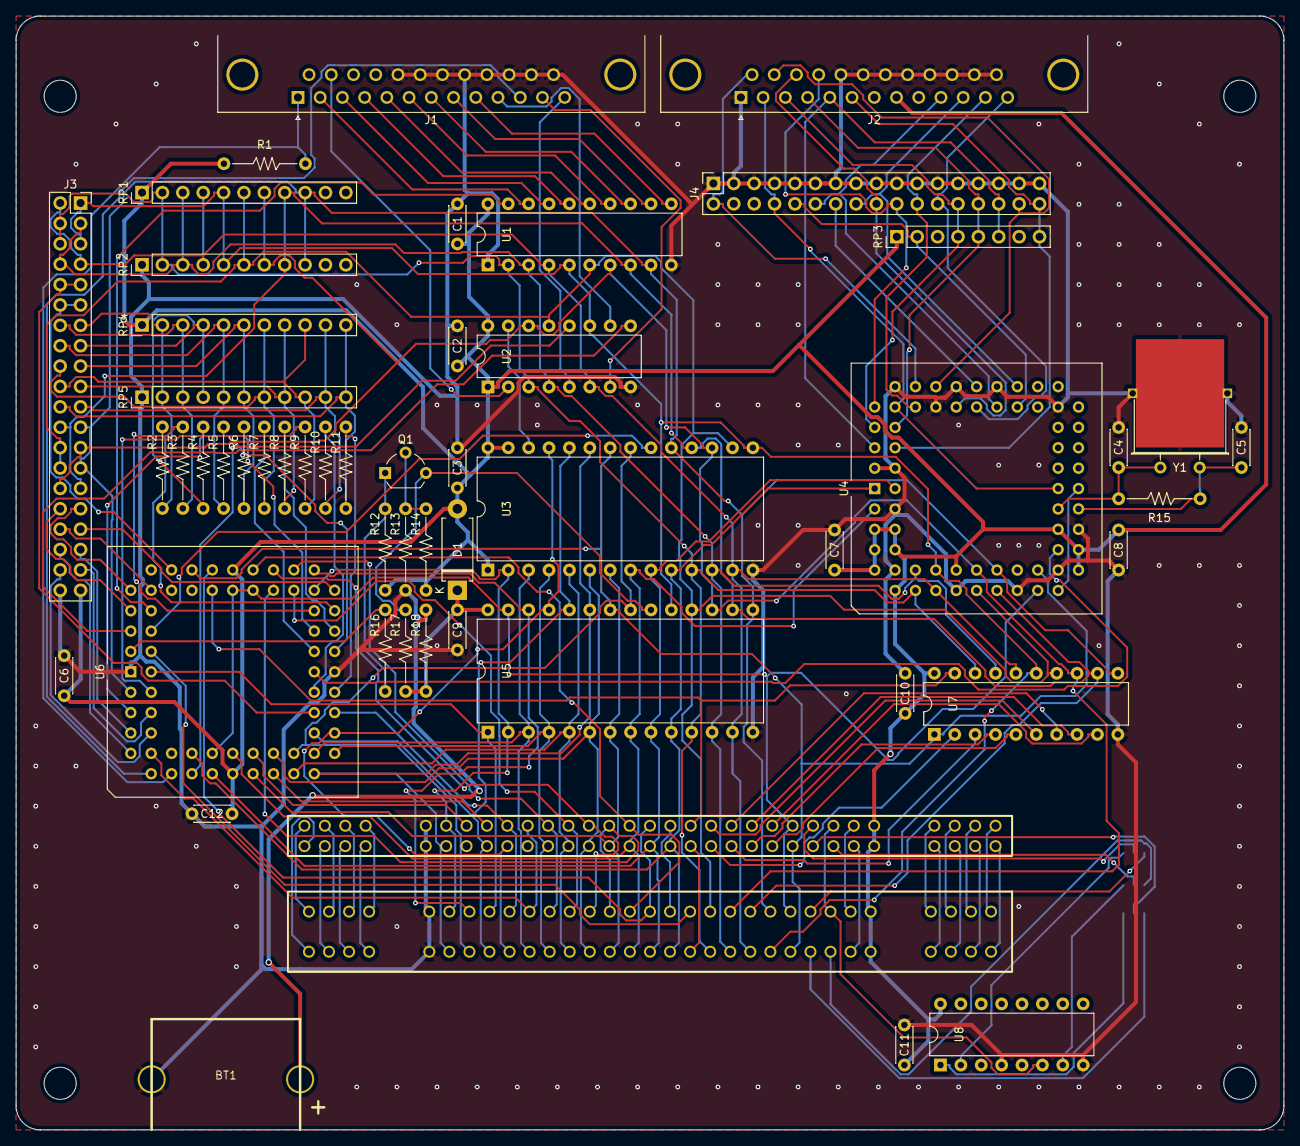
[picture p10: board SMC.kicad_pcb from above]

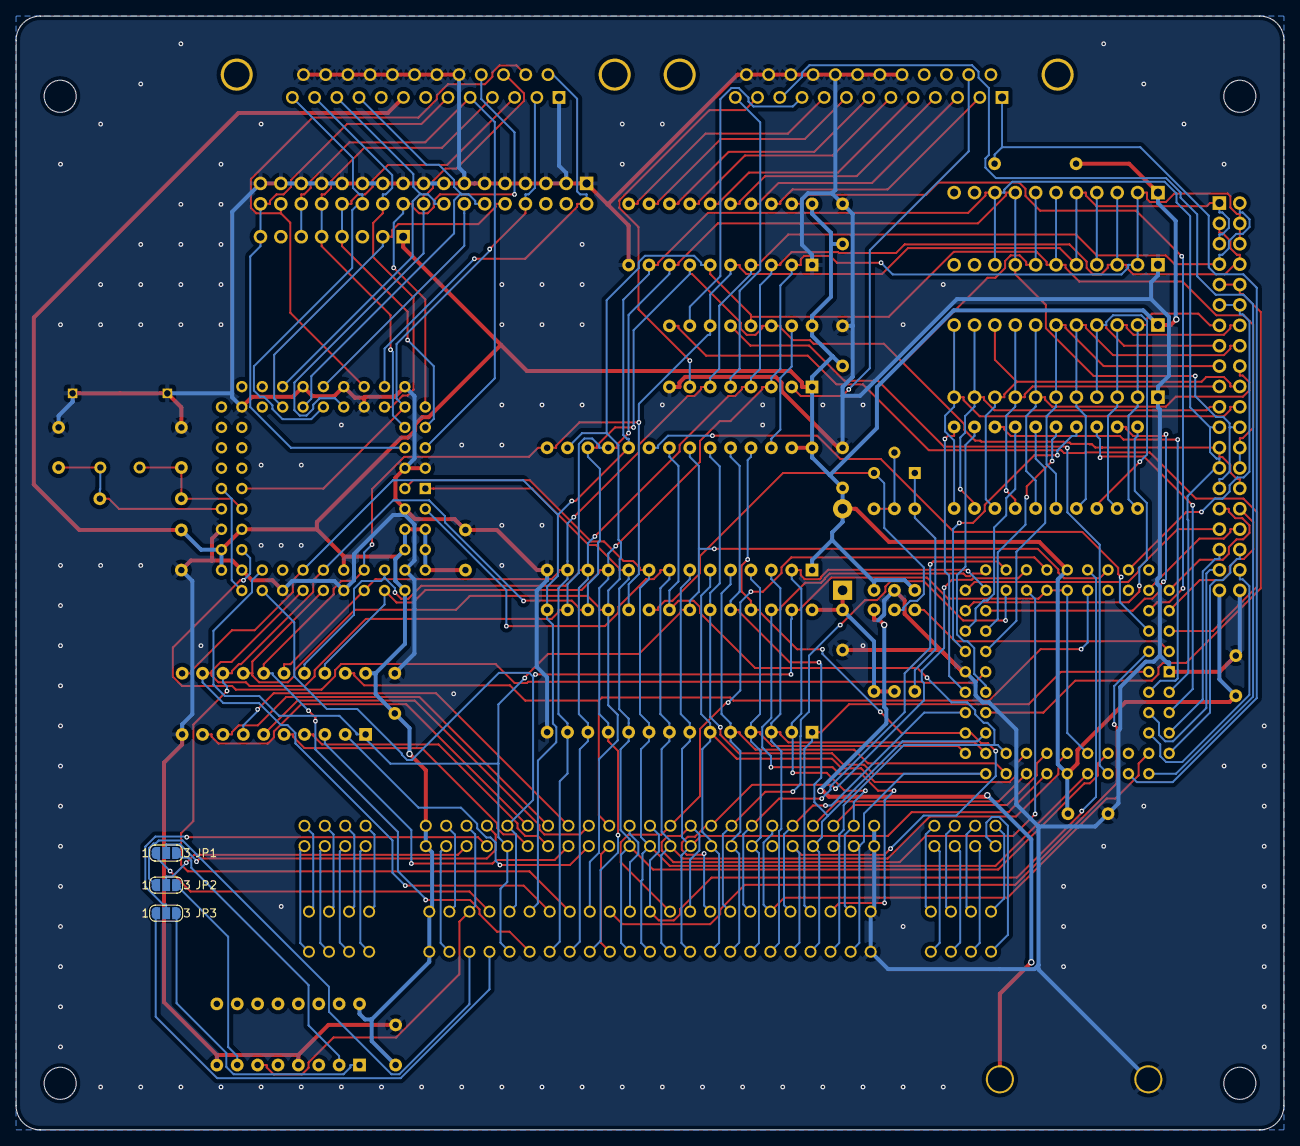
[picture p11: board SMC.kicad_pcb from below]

Board: 2 copper layers, 158.0 x 138.8 mm, 56 parts (3 on the bottom side), 151 nets.
